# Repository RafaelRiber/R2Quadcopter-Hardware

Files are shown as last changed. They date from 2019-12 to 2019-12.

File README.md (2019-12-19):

# R2Quadcopter-Hardware

<p align="center">
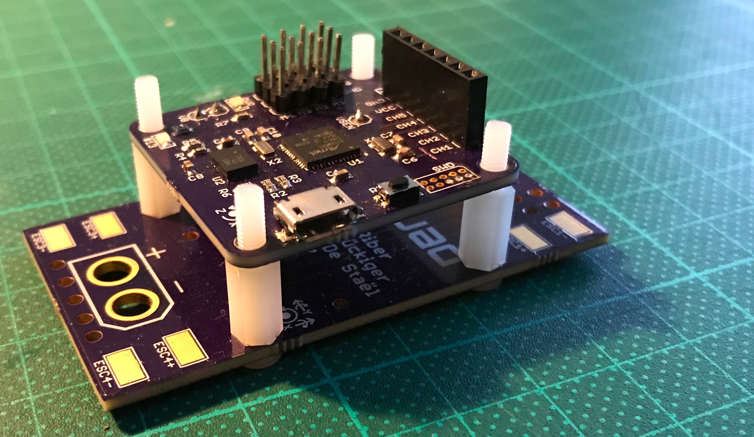
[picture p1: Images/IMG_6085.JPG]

</p>

<p align="center">
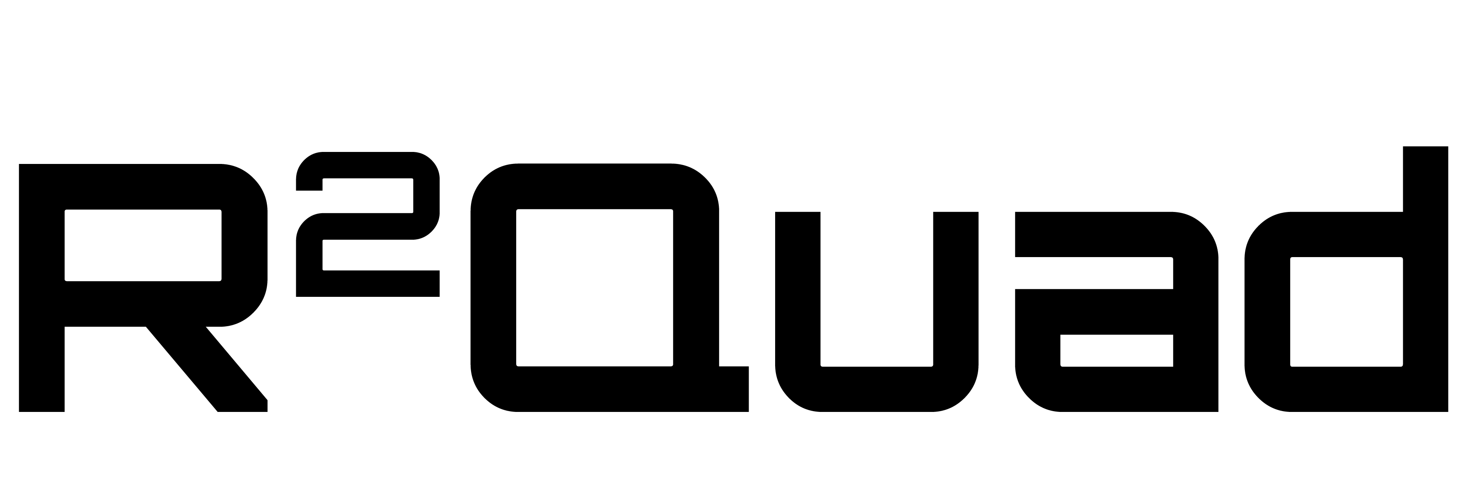
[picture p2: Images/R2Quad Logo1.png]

</p>

# Description

The R<sup>2</sup>Quad is an ARM Cortex M0+ Processor-Based radio controlled quadcopter flight controller.

<p align="center">

</p>

<p align="center">
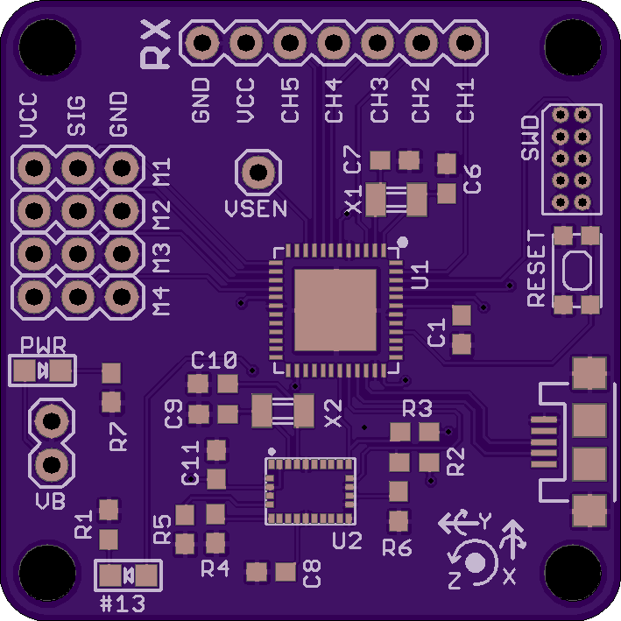
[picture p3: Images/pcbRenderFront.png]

</p>

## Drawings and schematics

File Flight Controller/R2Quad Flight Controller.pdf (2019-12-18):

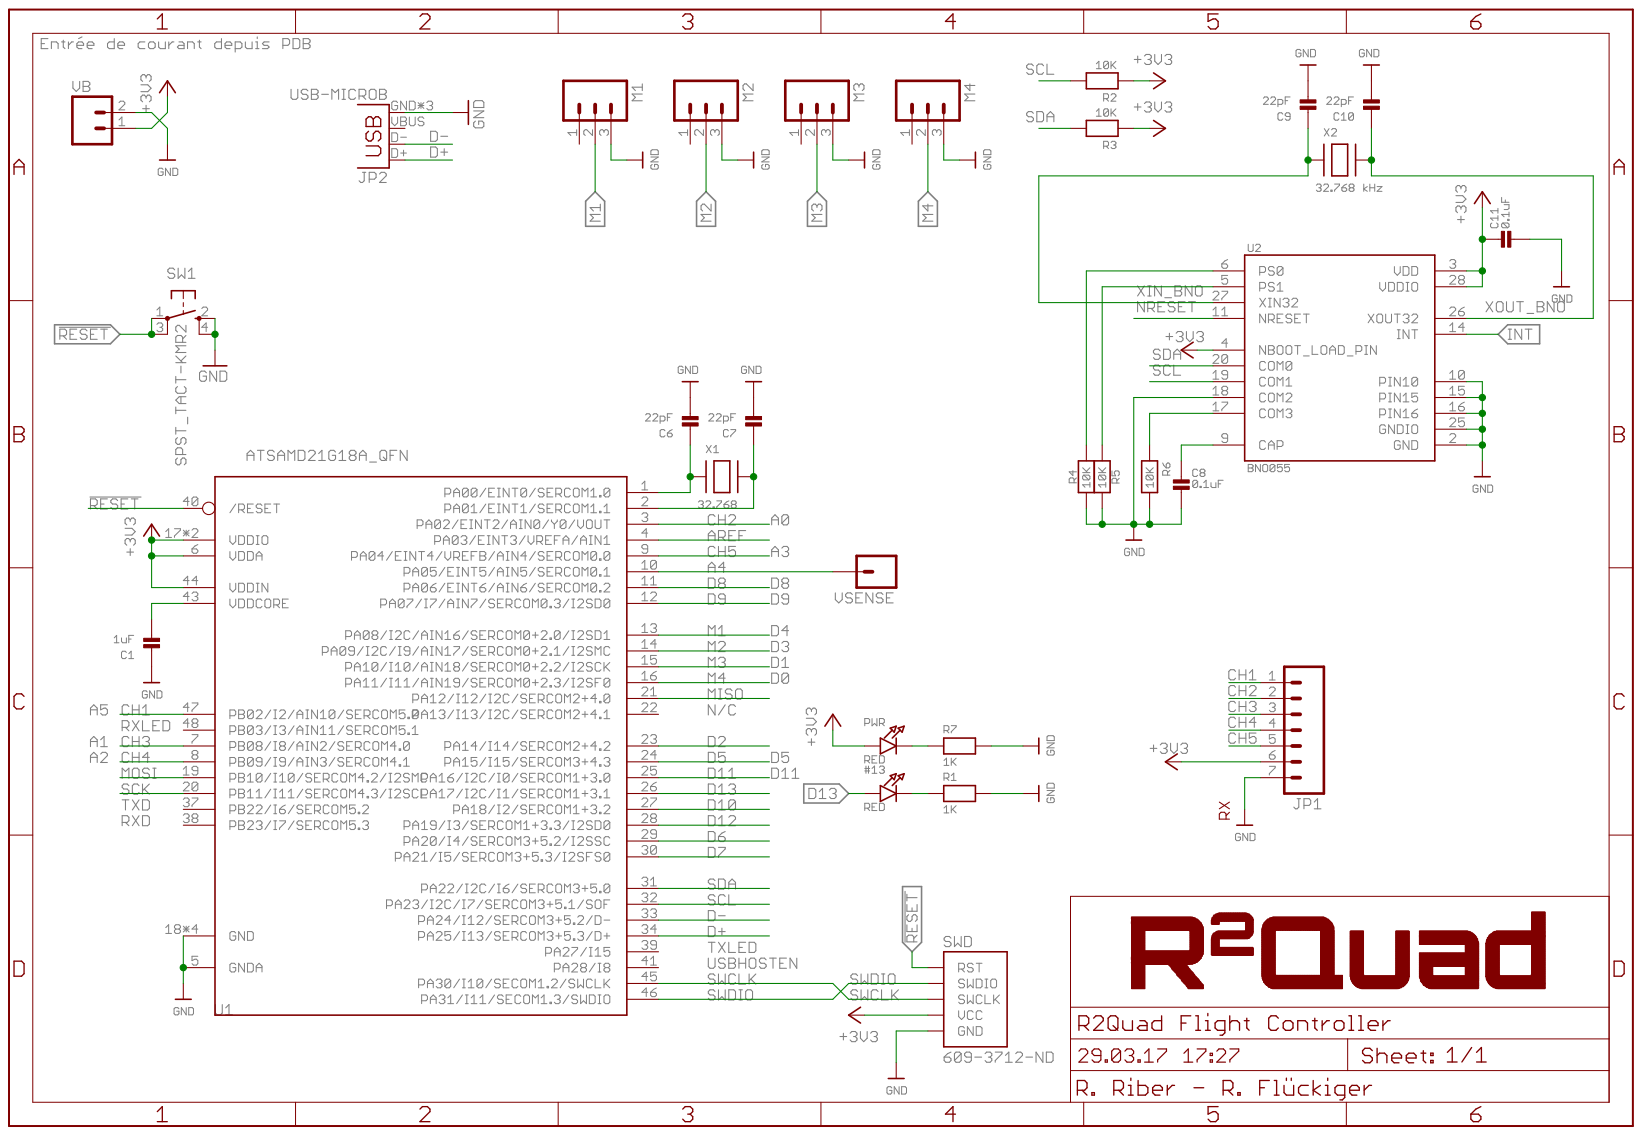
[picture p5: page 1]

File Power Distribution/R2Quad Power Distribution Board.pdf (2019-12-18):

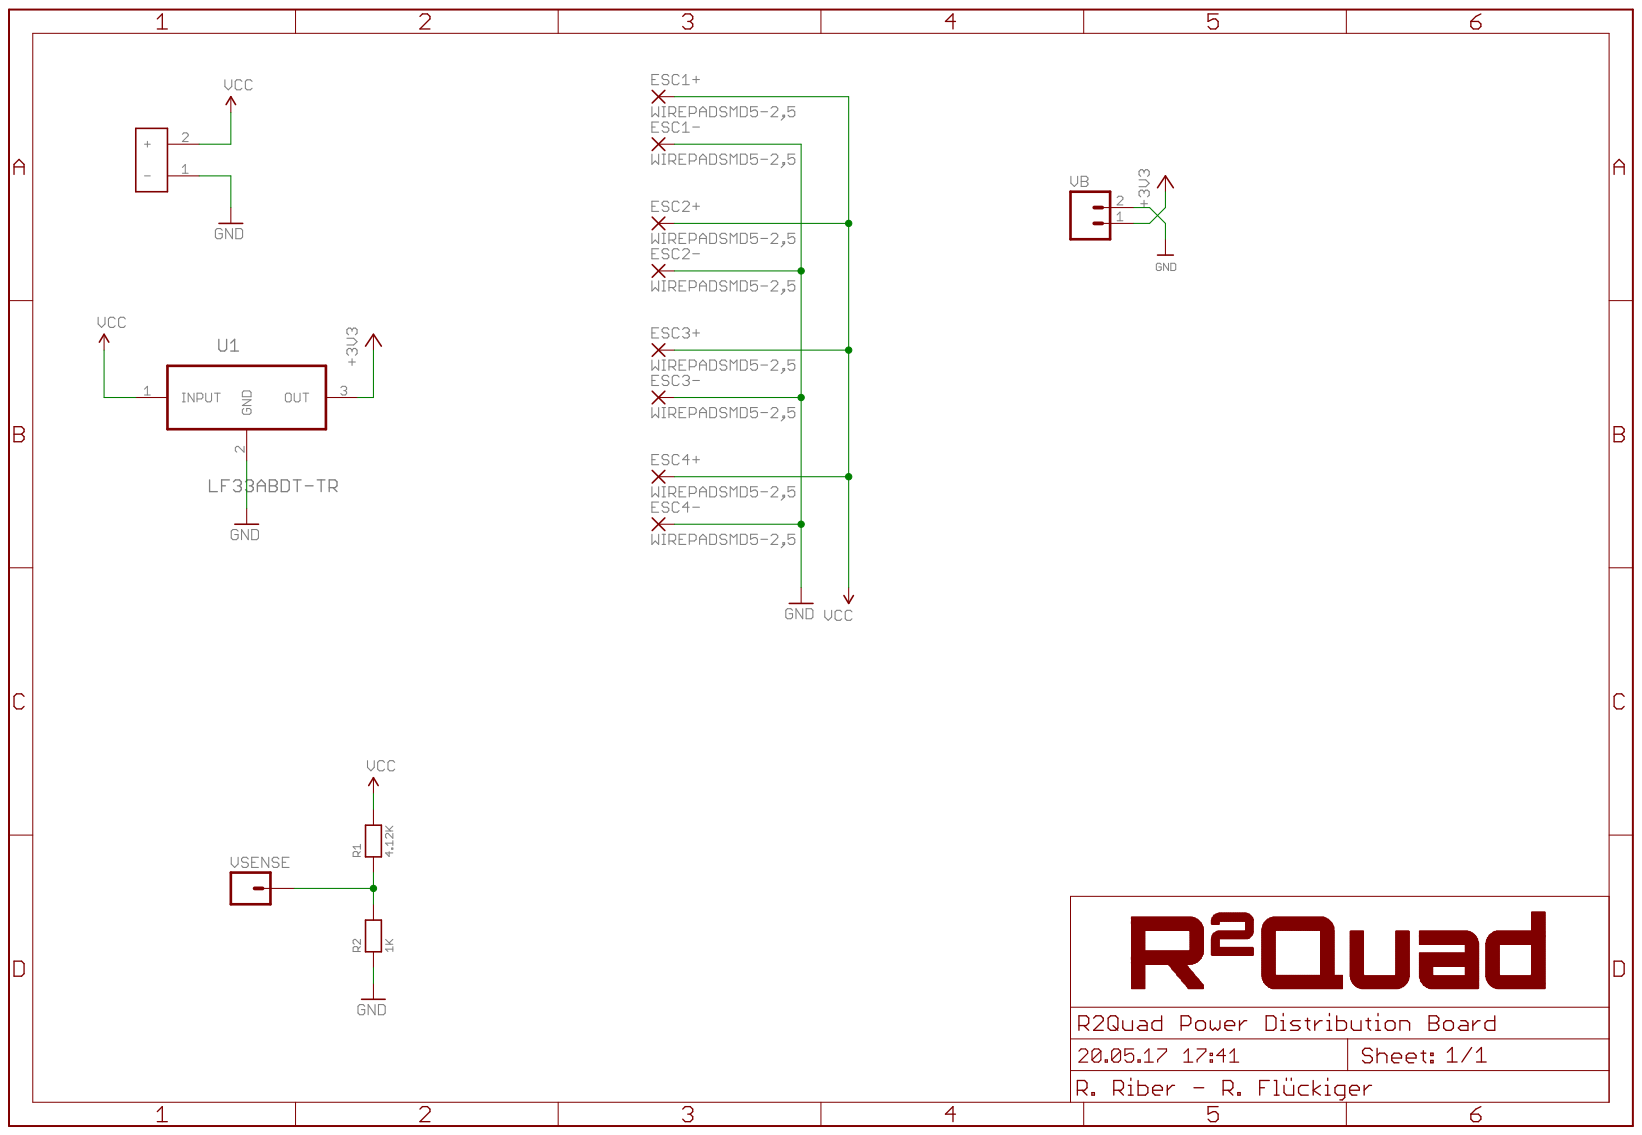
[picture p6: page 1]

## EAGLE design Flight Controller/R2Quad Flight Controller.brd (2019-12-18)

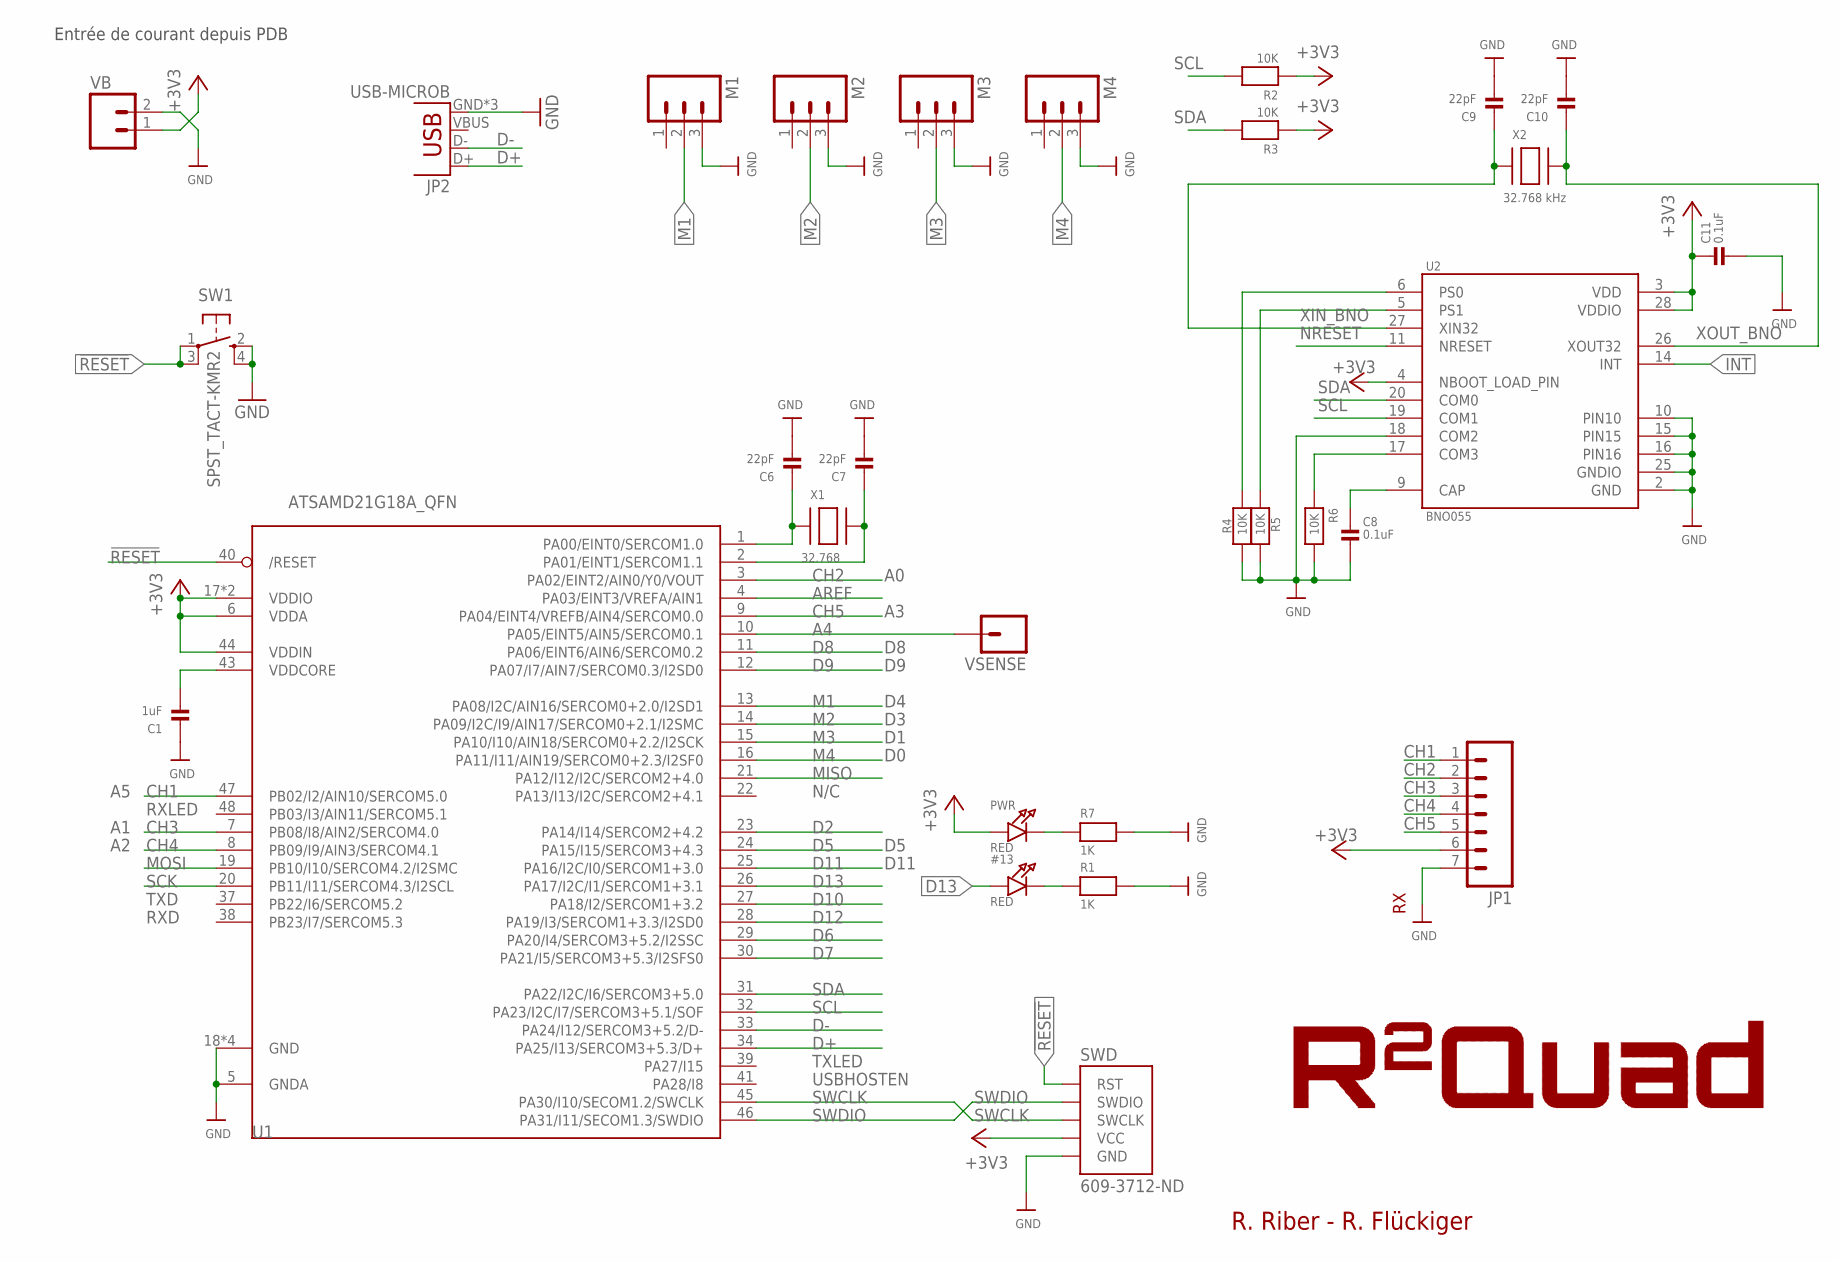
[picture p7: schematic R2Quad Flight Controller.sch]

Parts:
#13: RED; CHIPLED_0805; MPN LGQ971
C1: 1uF; 0603
C6, C7, C9, C10: 22pF; 0603
C8, C11: 0.1uF; 0603
JP1: M07; 1X07
JP2: USB-MICROB; MPN 10104110-0001LF
M1, M2, M3, M4: M03PTH; 1X03
PWR: RED; CHIPLED_0805; MPN LGQ971
R1, R7: 1K; 0603; MPN CRCW06032K20JNEA
R2, R3, R4, R5, R6: 10K; 0603; MPN CRCW060310K0FKEA
SW1: SPST_TACT-KMR2; KMR2
SWD: 609-3712-ND; SWD-2X5
U1: ATSAMD21G18A_QFN; TQFN48_7MM
U2: BNO055; LGA28R50P4X10_380X520X100
VB: M02PTH; 1X02
VSENSE: M01PTH; 1X01
X1: 32.768; XTAL3215
X2: 32.768 kHz; XTAL3215

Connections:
!RESET: SW1.1, SW1.3 (P1), SWD.RST, U1.40 (/RESET)
+3V3: C11.2, JP1.6, PWR.A, R2.1, R3.1, SWD.VCC, U1.6 (VDDA), U1.17 (VDDIO), U1.36 (VDDIO), U1.44 (VDDIN), U2.3 (VDD), U2.4 (NBOOT_LOAD_PIN), U2.28 (VDDIO), VB.1
A4: U1.10 (PA05/EINT5/AIN5/SERCOM0.1), VSENSE.1
AREF: U1.4 (PA03/EINT3/VREFA/AIN1)
CH1: JP1.1, U1.47 (PB02/I2/AIN10/SERCOM5.0)
CH2: JP1.2, U1.3 (PA02/EINT2/AIN0/Y0/VOUT)
CH3: JP1.3, U1.7 (PB08/I8/AIN2/SERCOM4.0)
CH4: JP1.4, U1.8 (PB09/I9/AIN3/SERCOM4.1)
CH5: JP1.5, U1.9 (PA04/EINT4/VREFB/AIN4/SERCOM0.0)
D2: U1.23 (PA14/I14/SERCOM2+4.2)
D5: U1.24 (PA15/I15/SERCOM3+4.3)
D6: U1.29 (PA20/I4/SERCOM3+5.2/I2SSC)
D7: U1.30 (PA21/I5/SERCOM3+5.3/I2SFS0)
D8: U1.11 (PA06/EINT6/AIN6/SERCOM0.2)
D9: U1.12 (PA07/I7/AIN7/SERCOM0.3/I2SD0)
D10: U1.27 (PA18/I2/SERCOM1+3.2)
D11: U1.25 (PA16/I2C/I0/SERCOM1+3.0)
D12: U1.28 (PA19/I3/SERCOM1+3.3/I2SD0)
D13: #13.A, U1.26 (PA17/I2C/I1/SERCOM1+3.1)
D+: JP2.D+, U1.34 (PA25/I13/SERCOM3+5.3/D+)
D-: JP2.D-, U1.33 (PA24/I12/SERCOM3+5.2/D-)
GND: C1.1, C6.2, C7.2, C8.1, C9.2, C10.2, C11.1, JP1.7, JP2.GND, JP2.MT1 (GND), JP2.MT2 (GND), M1.3, M2.3, M3.3, M4.3, R1.2, R4.2, R5.2, R6.2, R7.2, SW1.2 (S), SW1.4 (S1), SWD.GND@1 (GND), SWD.GND@2 (GND), SWD.GND@3 (GND), U1.5 (GNDA), U1.18 (GND), U1.35 (GND), U1.42 (GND), U1.THERMAL (GND), U2.2 (GND), U2.10 (PIN10), U2.15 (PIN15), U2.16 (PIN16), U2.18 (COM2), U2.25 (GNDIO), VB.2
INT: U2.14 (INT)
M1: M1.2, U1.13 (PA08/I2C/AIN16/SERCOM0+2.0/I2SD1)
M2: M2.2, U1.14 (PA09/I2C/I9/AIN17/SERCOM0+2.1/I2SMC)
M3: M3.2, U1.15 (PA10/I10/AIN18/SERCOM0+2.2/I2SCK)
M4: M4.2, U1.16 (PA11/I11/AIN19/SERCOM0+2.3/I2SF0)
MISO: U1.21 (PA12/I12/I2C/SERCOM2+4.0)
MOSI: U1.19 (PB10/I10/SERCOM4.2/I2SMC)
unnamed: PWR.C, R7.1
unnamed: C8.2, U2.9 (CAP)
unnamed: R6.1, U2.17 (COM3)
unnamed: R5.1, U2.5 (PS1)
unnamed: R4.1, U2.6 (PS0)
unnamed: C6.1, U1.1 (PA00/EINT0/SERCOM1.0), X1.P$1
unnamed: C7.1, U1.2 (PA01/EINT1/SERCOM1.1), X1.P$2
unnamed: #13.C, R1.1
NRESET: U2.11 (NRESET)
SCK: U1.20 (PB11/I11/SERCOM4.3/I2SCL)
SCL: R2.2, U1.32 (PA23/I2C/I7/SERCOM3+5.1/SOF), U2.19 (COM1)
SDA: R3.2, U1.31 (PA22/I2C/I6/SERCOM3+5.0), U2.20 (COM0)
SWCLK: SWD.SWCLK, U1.45 (PA30/I10/SECOM1.2/SWCLK)
SWDIO: SWD.SWDIO, U1.46 (PA31/I11/SECOM1.3/SWDIO)
VDDCORE1: C1.2, U1.43 (VDDCORE)
XIN_BNO: C9.1, U2.27 (XIN32), X2.P$1
XOUT_BNO: C10.1, U2.26 (XOUT32), X2.P$2

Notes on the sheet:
N/C
TXLED
USBHOSTEN
RXLED
TXD
RXD
D11
R. Riber - R. Flückiger
Entrée de courant depuis PDB

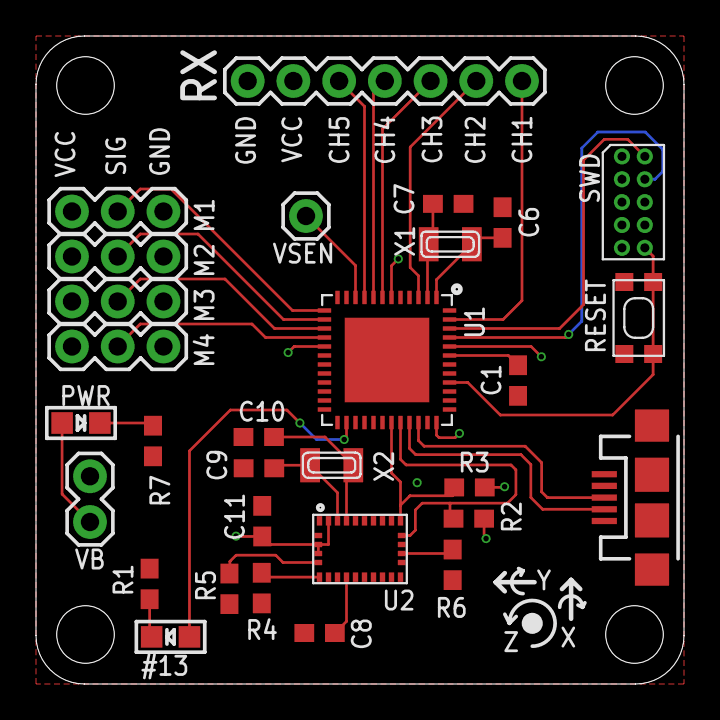
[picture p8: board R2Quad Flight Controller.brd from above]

Board: 4 copper layers, 36.0 x 36.0 mm, 32 parts (1 on the bottom side), 31 nets.

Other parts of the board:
U$1: R2QUAD_LOGO
U$2: SENSOR_AXIS

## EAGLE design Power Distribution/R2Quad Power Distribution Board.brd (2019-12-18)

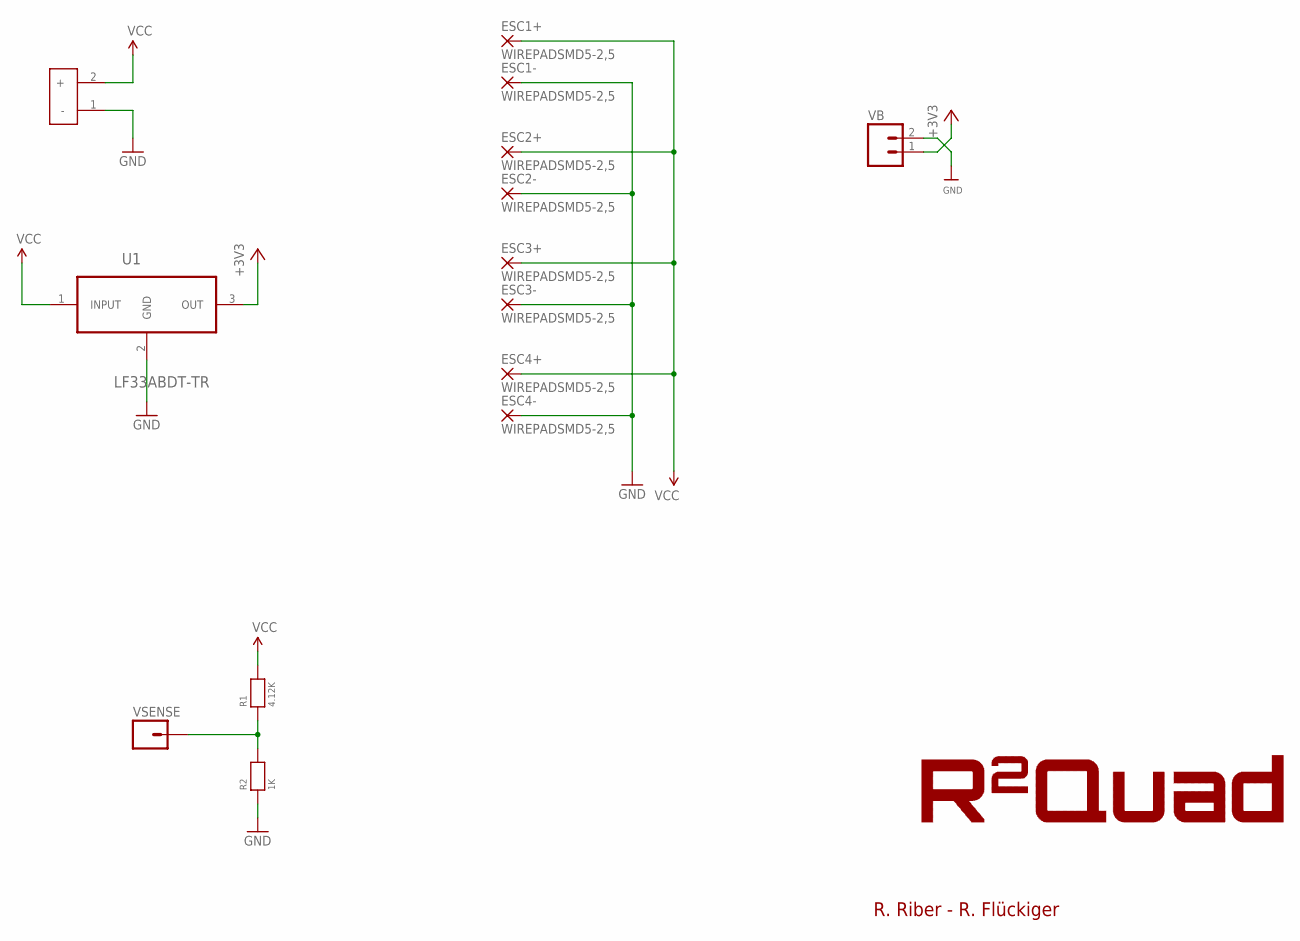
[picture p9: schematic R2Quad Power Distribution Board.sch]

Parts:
ESC1+, ESC1-, ESC2+, ESC2-, ESC3+, ESC3-, ESC4+, ESC4-: WIREPADSMD5-2,5; 5-2,5
R1: 4.12K; 0603
R2: 1K; 0603
U1: LF33ABDT-TR; TO228P972X240-3N
U$1: XT60
VB: M02PTH; 1X02
VSENSE: M01PTH; 1X01

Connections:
+3V3: U1.3 (OUT), VB.1
GND: ESC1-.1, ESC2-.1, ESC3-.1, ESC4-.1, R2.1, U1.2 (GND), U$1.1 (-), VB.2
unnamed: R1.1, R2.2, VSENSE.1
VCC: ESC1+.1, ESC2+.1, ESC3+.1, ESC4+.1, R1.2, U1.1 (INPUT), U$1.2 (+)

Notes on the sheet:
R. Riber - R. Flückiger

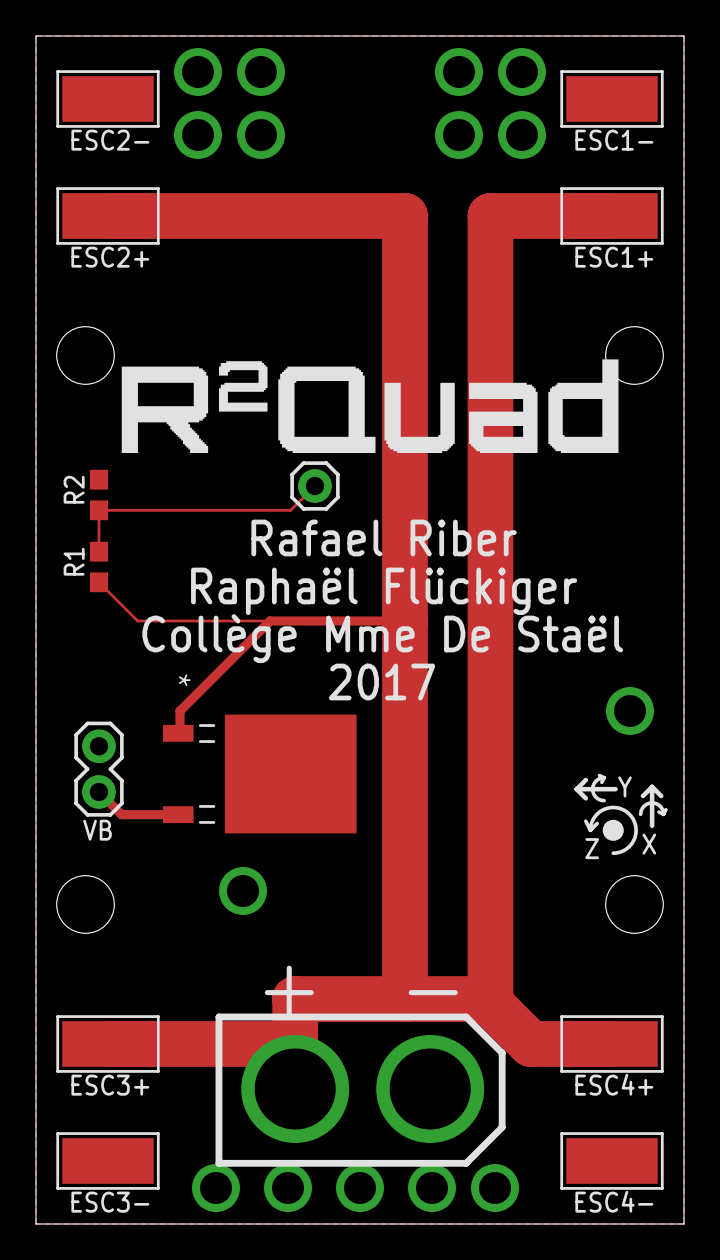
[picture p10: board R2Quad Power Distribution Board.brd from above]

Board: 2 copper layers, 36.0 x 66.0 mm, 16 parts (0 on the bottom side), 4 nets.

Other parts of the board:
U$2: R2QUAD_LOGO
U$3: SENSOR_AXIS

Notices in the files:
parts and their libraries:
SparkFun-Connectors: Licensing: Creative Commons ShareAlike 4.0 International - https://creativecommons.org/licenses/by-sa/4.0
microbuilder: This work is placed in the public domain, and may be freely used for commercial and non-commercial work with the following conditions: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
